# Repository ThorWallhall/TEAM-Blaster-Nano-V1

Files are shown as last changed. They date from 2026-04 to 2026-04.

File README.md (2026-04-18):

# T.E.A.M. Blaster Nano V1

**Open-source prop electronics kit for makers, cosplayers, and fandom builders.**  
**Open-Source-Elektronikkit für Maker, Cosplayer und Fandom-Bastler.**

[🇬🇧 English](#english) · [🇩🇪 Deutsch](#deutsch)

---

## English

### Overview

The T.E.A.M. Blaster Nano V1 is a compact all-in-one electronics board for
button-triggered sound and light effects in DIY props — fandom blasters,
sci-fi phasers, lightsabers and similar projects. A single button press plays
an audio sample through the onboard DFPlayer Mini while flashing an LED in sync.

### Features

- Button-triggered audio playback with synchronized LED effect
- Integrated Li-Ion battery charging over USB-C (**TP4056**)
- Battery protection circuit (**DW01A + FS8205A** dual MOSFET)
- Boost converter for a stable supply rail (**MT3608**)
- **ATmega328P-AU** microcontroller — Arduino Nano compatible
- Onboard USB-UART bridge (**CH340G**) — flash firmware directly via USB-C
- Compact form factor with JST-XH connectors for battery, speaker, button, LED

### Hardware

| Block | Part | Package |
|---|---|---|
| Microcontroller | ATmega328P-AU | TQFP-32 |
| Audio player | DFPlayer Mini (DFR0299)  | module |
| Battery charger | TP4056 | SOIC-8-1EP |
| Battery protection  | DW01A + FS8205A | SOT-23-6 + TSSOP-8 |
| Boost converter | MT3608 | SOT-23-6 |
| USB-UART bridge | CH340G | SOIC-16 |
| USB input | USB-C (GCT USB4085) | — |

Full bill of materials in `Dokumentation/`.

### Repository Structure

```
├── Code T.E.A.M. - Blaster Nano V1/   → firmware (PlatformIO / Arduino)
├── Dokumentation/                     → BOM, datasheets
├── KiCAD/                             → schematic + PCB design files
├── ASSEMBLY.md                        → ⚠️ assembly & safety notes
└── README.md                          → this file
```

### Firmware

Written in C++11 for the Arduino framework. Builds with either the Arduino IDE
or PlatformIO.

Dependencies:

- `Arduino.h` *(core)*
- `SoftwareSerial.h` *(core)*
- `DFRobotDFPlayerMini` *(install via library manager)*

### ⚠️ Assembly

**Before first power-on, read [`ASSEMBLY.md`](ASSEMBLY.md).**
It contains critical polarity information for the JST-XH connectors —
wrong polarity can destroy the battery cell or the protection circuit.

### License

MIT License — see the `LICENSE` file for details.

### Author

T.E.A.M. — *for your fandom* · © 2026

---

## Deutsch

### Überblick

Der T.E.A.M. Blaster Nano V1 ist eine kompakte All-in-One-Elektronikplatine
für taster-ausgelöste Sound- und Lichteffekte in Eigenbau-Props — Fandom-Blaster,
Sci-Fi-Phaser, Lichtschwerter und ähnliche Projekte. Ein Tastendruck spielt ein
Audio-Sample über das integrierte DFPlayer-Mini-Modul und lässt synchron dazu
eine LED aufleuchten.

### Funktionen

- Taster-ausgelöste Audio-Wiedergabe mit synchronem LED-Effekt
- Integrierte Li-Ion-Akkuladung über USB-C (**TP4056**)
- Schutzschaltung für den Akku (**DW01A + FS8205A** Dual-MOSFET)
- Step-Up-Wandler für stabile Versorgungsspannung (**MT3608**)
- **ATmega328P-AU** Mikrocontroller — Arduino-Nano-kompatibel
- Integrierter USB-UART-Bridge (**CH340G**) — Firmware direkt über USB-C flashen
- Kompaktes Format mit JST-XH-Steckern für Akku, Lautsprecher, Taster, LED

### Hardware

| Block | Bauteil | Gehäuse |
|---|---|---|
| Mikrocontroller | ATmega328P-AU | TQFP-32 |
| Audio-Player | DFPlayer Mini (DFR0299)  | Modul |
| Akku-Lader | TP4056 | SOIC-8-1EP |
| Akku-Schutz | DW01A + FS8205A | SOT-23-6 + TSSOP-8 |
| Step-Up-Wandler | MT3608 | SOT-23-6 |
| USB-UART-Bridge | CH340G | SOIC-16 |
| USB-Eingang | USB-C (GCT USB4085) | — |

Die vollständige Stückliste liegt im Ordner `Dokumentation/`.

### Repository-Struktur

```
├── Code T.E.A.M. - Blaster Nano V1/   → Firmware (PlatformIO / Arduino)
├── Dokumentation/                     → Stückliste, Datenblätter
├── KiCAD/                             → Schaltplan + PCB-Entwurfsdaten
├── ASSEMBLY.md                        → ⚠️ Montage- & Sicherheitshinweise
└── README.md                          → diese Datei
```

### Firmware

Geschrieben in C++11 für das Arduino-Framework. Lässt sich sowohl mit der
Arduino IDE als auch mit PlatformIO bauen.

Abhängigkeiten:

- `Arduino.h` *(Kern)*
- `SoftwareSerial.h` *(Kern)*
- `DFRobotDFPlayerMini` *(über Library Manager installieren)*

### ⚠️ Montage

**Vor dem ersten Einschalten unbedingt [`ASSEMBLY.md`](ASSEMBLY.md) lesen.**
Dort stehen wichtige Polungshinweise zu den JST-XH-Steckern —
falsche Polung kann den Akku oder die Schutzschaltung zerstören.

### Lizenz

MIT-Lizenz — Details in der Datei `LICENSE`.

### Autor

T.E.A.M. — *for your fandom* · © 2026

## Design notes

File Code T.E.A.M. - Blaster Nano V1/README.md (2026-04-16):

# TEAM-Blaster-Nano-V1
T.E.A.M. Blaster Nano V1 - Prop Electronics Kit

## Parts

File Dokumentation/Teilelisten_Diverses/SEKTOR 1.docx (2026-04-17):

SEKTOR 1 — POWER (final)

Bauteil | Gehäuse | Funktion
TP4056 | SOP-8 | LiPo-Lade IC
DW01A | SOT-23-6 | Akku-Schutz
FS8205A | SOT-23-6 | Dual MOSFET für DW01A
USB-C Buchse (J1) | SMD | Laden + Programmieren
14500 LiPo | — | Stromquelle
JST-XH 2,5mm (J2) | 2-Pin | Akku-Anschluss
LED rot | SMD | Ladeanzeige (CHRG)
LED grün | SMD | Vollanzeige (STDBY)
R 1kΩ | 0402 | ×2, Vorwiderstand LEDs
R 2,4kΩ | 0402 | PROG Ladestrom 500mA
C 100nF | 0402 | Bypass VCC
C 10µF | 0805 | Stützkondensator BAT

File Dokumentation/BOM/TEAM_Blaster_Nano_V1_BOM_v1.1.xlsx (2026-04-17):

T.E.A.M. Blaster Nano V1 — Bill of Materials (aus KiCad Schematic)
Rev. 1.1 | Datum: 2026-04-17 | MCU: ATmega328P-AU (TQFP-32) + CH340G | Autor: T.E.A.M. - for your fandom
Ref | Wert / Typ | Menge | Hersteller | Bestellnummer (Beispiel) | Footprint | Package | Preis/Stk (€) | Gesamt (€) | Funktion / Bemerkung
USB-Ladeschaltung (TP4056 ESOP-8)
U1 | TP4056-42-ESOP8 | 1 | NanJing Top Power | TP4056-42-ESOP8 (LCSC: C16581) | SOIC-8_3.9x4.9mm_P1.27mm | ESOP-8 | 0.25 € | 0.25 € | LiPo-Lader 4,2 V; CC/CV; Thermoschutz
J1 | USB-C Buchse 14P | 1 | GCT | USB4085-GF-A | USB_C_Receptacle_GCT_USB4085 | SMD 14-Pin | 0.55 € | 0.55 € | Ladeeingang 5 V USB
R3 | 2k4 | 1 | Yageo | RC0402FR-072K4L | R_0402_1005Metric | 0402 | 0.02 € | 0.02 € | RPROG → I_CHG = 1200/2,4 = 500 mA
R10, R11 | 5k1 | 2 | Yageo | RC0402FR-075K1L | R_0402_1005Metric | 0402 | 0.02 € | 0.04 € | USB-C CC1/CC2 Pull-down (5,1 kΩ je)
D1 | LED rot | 1 | Würth | 150080RS75000 | LED_0805_2012Metric | 0805 | 0.05 € | 0.05 € | Charging-Status (TP4056 Pin CHRG)
D2 | LED blau | 1 | Würth | 150080BS75000 | LED_0805_2012Metric | 0805 | 0.06 € | 0.06 € | Standby/Full-Status (TP4056 Pin STDBY)
R1 | 1k (LED CHG) | 1 | Yageo | RC0402FR-071KL | R_0402_1005Metric | 0402 | 0.02 € | 0.02 € | Strombegrenzung D1
R2 | 1k (LED STDBY) | 1 | Yageo | RC0402FR-071KL | R_0402_1005Metric | 0402 | 0.02 € | 0.02 € | Strombegrenzung D2
C1 | 10 µF / 10 V | 1 | Murata | GRM21BR61A106KE19L | C_0805_2012Metric | 0805 | 0.08 € | 0.08 € | TP4056 VCC-Bypass
Batterieschutz (DW01A + FS8205A)
U2 | DW01A | 1 | Fortune Semi | DW01A-G | SOT-23-6 | SOT-23-6 | 0.12 € | 0.12 € | Über-/Unterspannungs- & Überstromschutz LiPo
Q1 | FS8205A | 1 | Fortune Semi | FS8205A | SOT-23-6 | SOT-23-6 | 0.18 € | 0.18 € | Dual N-Ch MOSFET; Lade-/Entlade-Schalter
R4 | 0,47 Ω | 1 | Yageo | RC0402FR-070R47L | R_0402_1005Metric | 0402 | 0.03 € | 0.03 € | Strommess-Shunt (CS-Pin DW01A)
R5 | 470 Ω | 1 | Yageo | RC0402FR-07470RL | R_0402_1005Metric | 0402 | 0.02 € | 0.02 € | ESD-Schutz VCC-Pin DW01A
J2 | JST XH 2-Pin (Batterie) | 1 | JST | B2B-XH-A | JST_XH_B2B-XH-A_1x02_P2.50mm_Vertical | THT | 0.20 € | 0.20 € | LiPo-Akkuanschluss 3,7 V
Spannungsbooster 3,7 V → ~4,6 V (MT3608)
U3 | MT3608 | 1 | Aerosemi | MT3608 (LCSC: C84697) | SOT-23-6 | SOT-23-6 | 0.20 € | 0.20 € | Step-Up; Vout=0,6×(1+R7/R8)=0,6×7,67≈4,6 V
L1, L2 | 10 µH / 1,5 A | 2 | Würth | 744043010 | L_0805_2012Metric | 0805 | 0.28 € | 0.56 € | Boost-Spulen parallel → höhere Stromtragfähigkeit
D3 | SS14 | 1 | Vishay | SS14-E3/61T | D_SMA | SMA (DO-214AC) | 0.10 € | 0.10 € | Freilaufdiode MT3608; 40 V / 1 A
C4 | 22 µF / 16 V | 1 | Murata | GRM21BR61C226ME44L | C_0805_2012Metric | 0805 | 0.12 € | 0.12 € | MT3608 Eingangs-Puffer
C5 | 22 µF / 16 V | 1 | Murata | GRM21BR61C226ME44L | C_0805_2012Metric | 0805 | 0.12 € | 0.12 € | MT3608 Ausgangs-Glättung
R7 | 180 kΩ | 1 | Yageo | RC0402FR-07180KL | R_0402_1005Metric | 0402 | 0.02 € | 0.02 € | Feedback-Teiler oben (Vout einstellen)
R8 | 27 kΩ | 1 | Yageo | RC0402FR-0727KL | R_0402_1005Metric | 0402 | 0.02 € | 0.02 € | Feedback-Teiler unten
Mikrocontroller ATmega328P-AU + CH340G
U4 | ATmega328P-AU | 1 | Microchip | ATMEGA328P-AU | TQFP-32_7x7mm_P0.8mm | TQFP-32 | 1.80 € | 1.80 € | Haupt-MCU; 16 MHz; 5 V; Arduino-kompatibel
U5 | CH340G | 1 | WCH | CH340G | SOIC-16_3.9x9.9mm_P1.27mm | SOIC-16 | 0.35 € | 0.35 € | USB-Seriell-Brücke für Programmierung
Y1 | 16 MHz | 1 | ABRACON | ABM3-16.000MHZ-D2Y-T | Crystal_SMD_3225-4Pin_3.2x2.5mm | SMD 3225 | 0.35 € | 0.35 € | Takt ATmega328P
Y2 | 12 MHz | 1 | ABRACON | ABM3-12.000MHZ-D2Y-T | Crystal_SMD_3225-4Pin_3.2x2.5mm | SMD 3225 | 0.35 € | 0.35 € | Takt CH340G
C11, C12 | 22 pF / 50 V | 2 | Samsung | CL05C220JB5NNNC | C_0402_1005Metric | 0402 | 0.03 € | 0.06 € | Load-Caps Y1 (ATmega)
C13, C14 | 22 pF / 50 V | 2 | Samsung | CL05C220JB5NNNC | C_0402_1005Metric | 0402 | 0.03 € | 0.06 € | Load-Caps Y2 (CH340G)
C2, C8 | 10 µF / 10 V | 2 | Murata | GRM21BR61A106KE19L | C_0805_2012Metric | 0805 | 0.08 € | 0.16 € | VCC-Bypass MCU / CH340G
C3,C6,C7,C9,C10,C15,C16 | 100 nF / 10 V | 7 | Samsung | CL05B104KO5NNNC | C_0402_1005Metric | 0402 | 0.03 € | 0.21 € | Entkopplungs-Caps (verteilt auf alle ICs)
R9 | 10 kΩ | 1 | Yageo | RC0402FR-0710KL | R_0402_1005Metric | 0402 | 0.02 € | 0.02 € | RESET Pull-up ATmega328P
J6 | ISP 2×3 Pfostenleiste | 1 | Würth | 61300621121 | PinHeader_2x03_P2.54mm_Vertical | THT 2,54 mm | 0.15 € | 0.15 € | In-System-Programmierung (MOSI/MISO/SCK/RST)
Audio (DFPlayer Mini DFR0299)
U6 | DFR0299 DFPlayer Mini | 1 | DFRobot | DFR0299 | MODULE_DFR0299 (Custom) | Modul | 2.80 € | 2.80 € | MP3/WAV; UART 9600; interner SD-Kartenleser
R6 | 1 kΩ (UART-RX) | 1 | Yageo | RC0402FR-071KL | R_0402_1005Metric | 0402 | 0.02 € | 0.02 € | Pegelschutz ATmega TX → DFPlayer RX
J3 | JST XH 2-Pin (LED) | 1 | JST | B2B-XH-A | JST_XH_B2B-XH-A_1x02_P2.50mm_Vertical | THT | 0.20 € | 0.20 € | Externer Blaster-LED-Anschluss
J4 | JST XH 2-Pin (Taster) | 1 | JST | B2B-XH-A | JST_XH_B2B-XH-A_1x02_P2.50mm_Vertical | THT | 0.20 € | 0.20 € | Trigger-Taster extern; Pin D3
J5 | JST XH 2-Pin (Speaker) | 1 | JST | B2B-XH-A | JST_XH_B2B-XH-A_1x02_P2.50mm_Vertical | THT | 0.20 € | 0.20 € | Lautsprecher 8 Ω an DFPlayer SPK1/SPK2
GESAMTKOSTEN (Einzelplatine, ohne Akku & Lautsprecher) |  |  |  |  |  |  |  | 9.71 € | Ohne MwSt. / ohne Versand / Richtpreise
⚠ Hinweise: R3=2k4 → I_CHG=500 mA (TP4056). L1+L2 je 10 µH parallel → erhöhte Stromtragfähigkeit. Vout(MT3608) = 0,6×(1+180k/27k) ≈ 4,6 V. Q1 (FS8205A) hat SOT-23-6 Footprint laut CSV (nicht TSSOP-8). Y2=12 MHz ist der Takt für den CH340G USB-Seriell-Chip. R10/R11 = 5k1 sind USB-C CC-Pull-downs (Pflicht für USB-C Power).

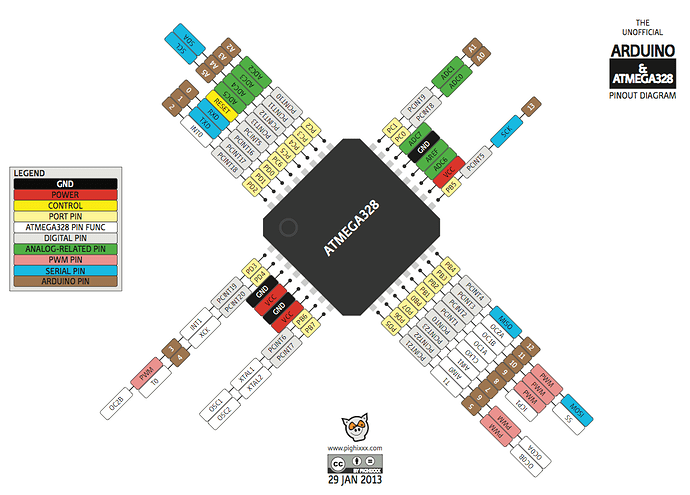
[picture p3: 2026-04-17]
Dokumentation/Teilelisten_Diverses/5d795ff3e6a315c0eee8202d54d3cbbd91941882_2_690x495.png

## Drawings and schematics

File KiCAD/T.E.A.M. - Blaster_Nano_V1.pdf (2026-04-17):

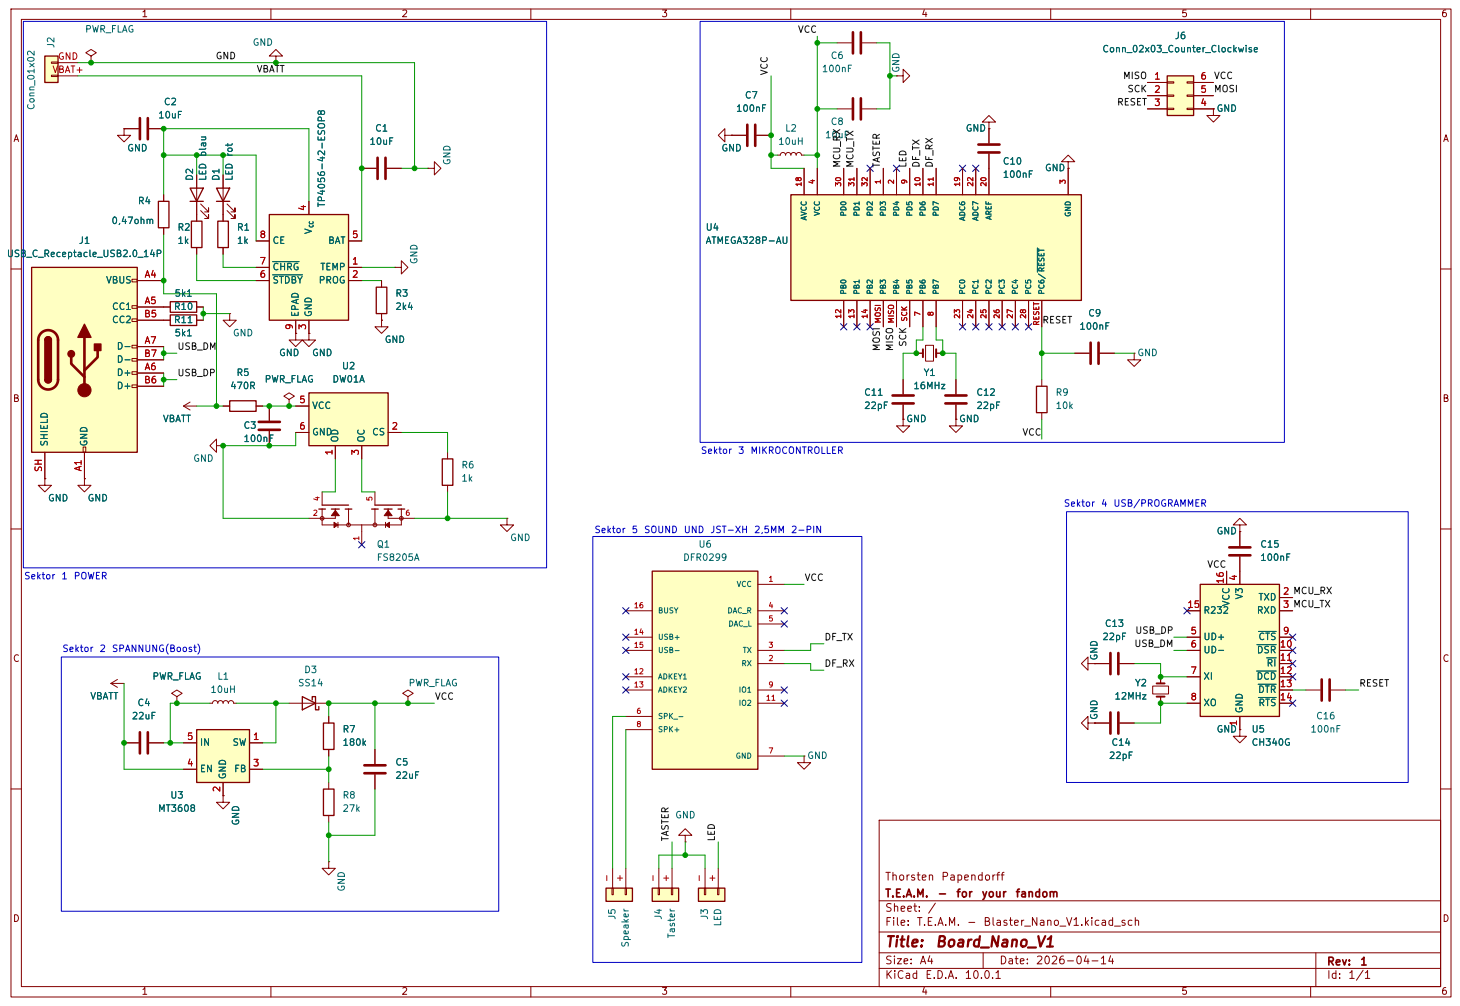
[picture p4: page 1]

MOSI Sektor 5 SOUND UND JST-XH 2,5MM 2-PIN

9 PD6 10 PD7 11 PB0 12 PB1 13 PB2 14 AVCC 18 ADC6 19 AREF 20 ADC7 22 PC0 23 PC1 24 PC2 25 PC3 26 PC4 27 PC5 28 PD0 30 PD1 31 PD2 32 PB4 MISO PB3 MOSI PC6/ RESET RESET PB5 SCK C7
GND U4

9 PD6 10 PD7 11 PB0 12 PB1 13 PB2 14 AVCC 18 ADC6 19 AREF 20 ADC7 22 PC0 23 PC1 24 PC2 25 PC3 26 PC4 27 PC5 28 PD0 30 PD1 31 PD2 32 PB4 MISO PB3 MOSI PC6/ RESET RESET PB5 SCK U4

Size: A4 | Rev: 1
KiCad E.D.A. 10.0.1 | Id: 1/1

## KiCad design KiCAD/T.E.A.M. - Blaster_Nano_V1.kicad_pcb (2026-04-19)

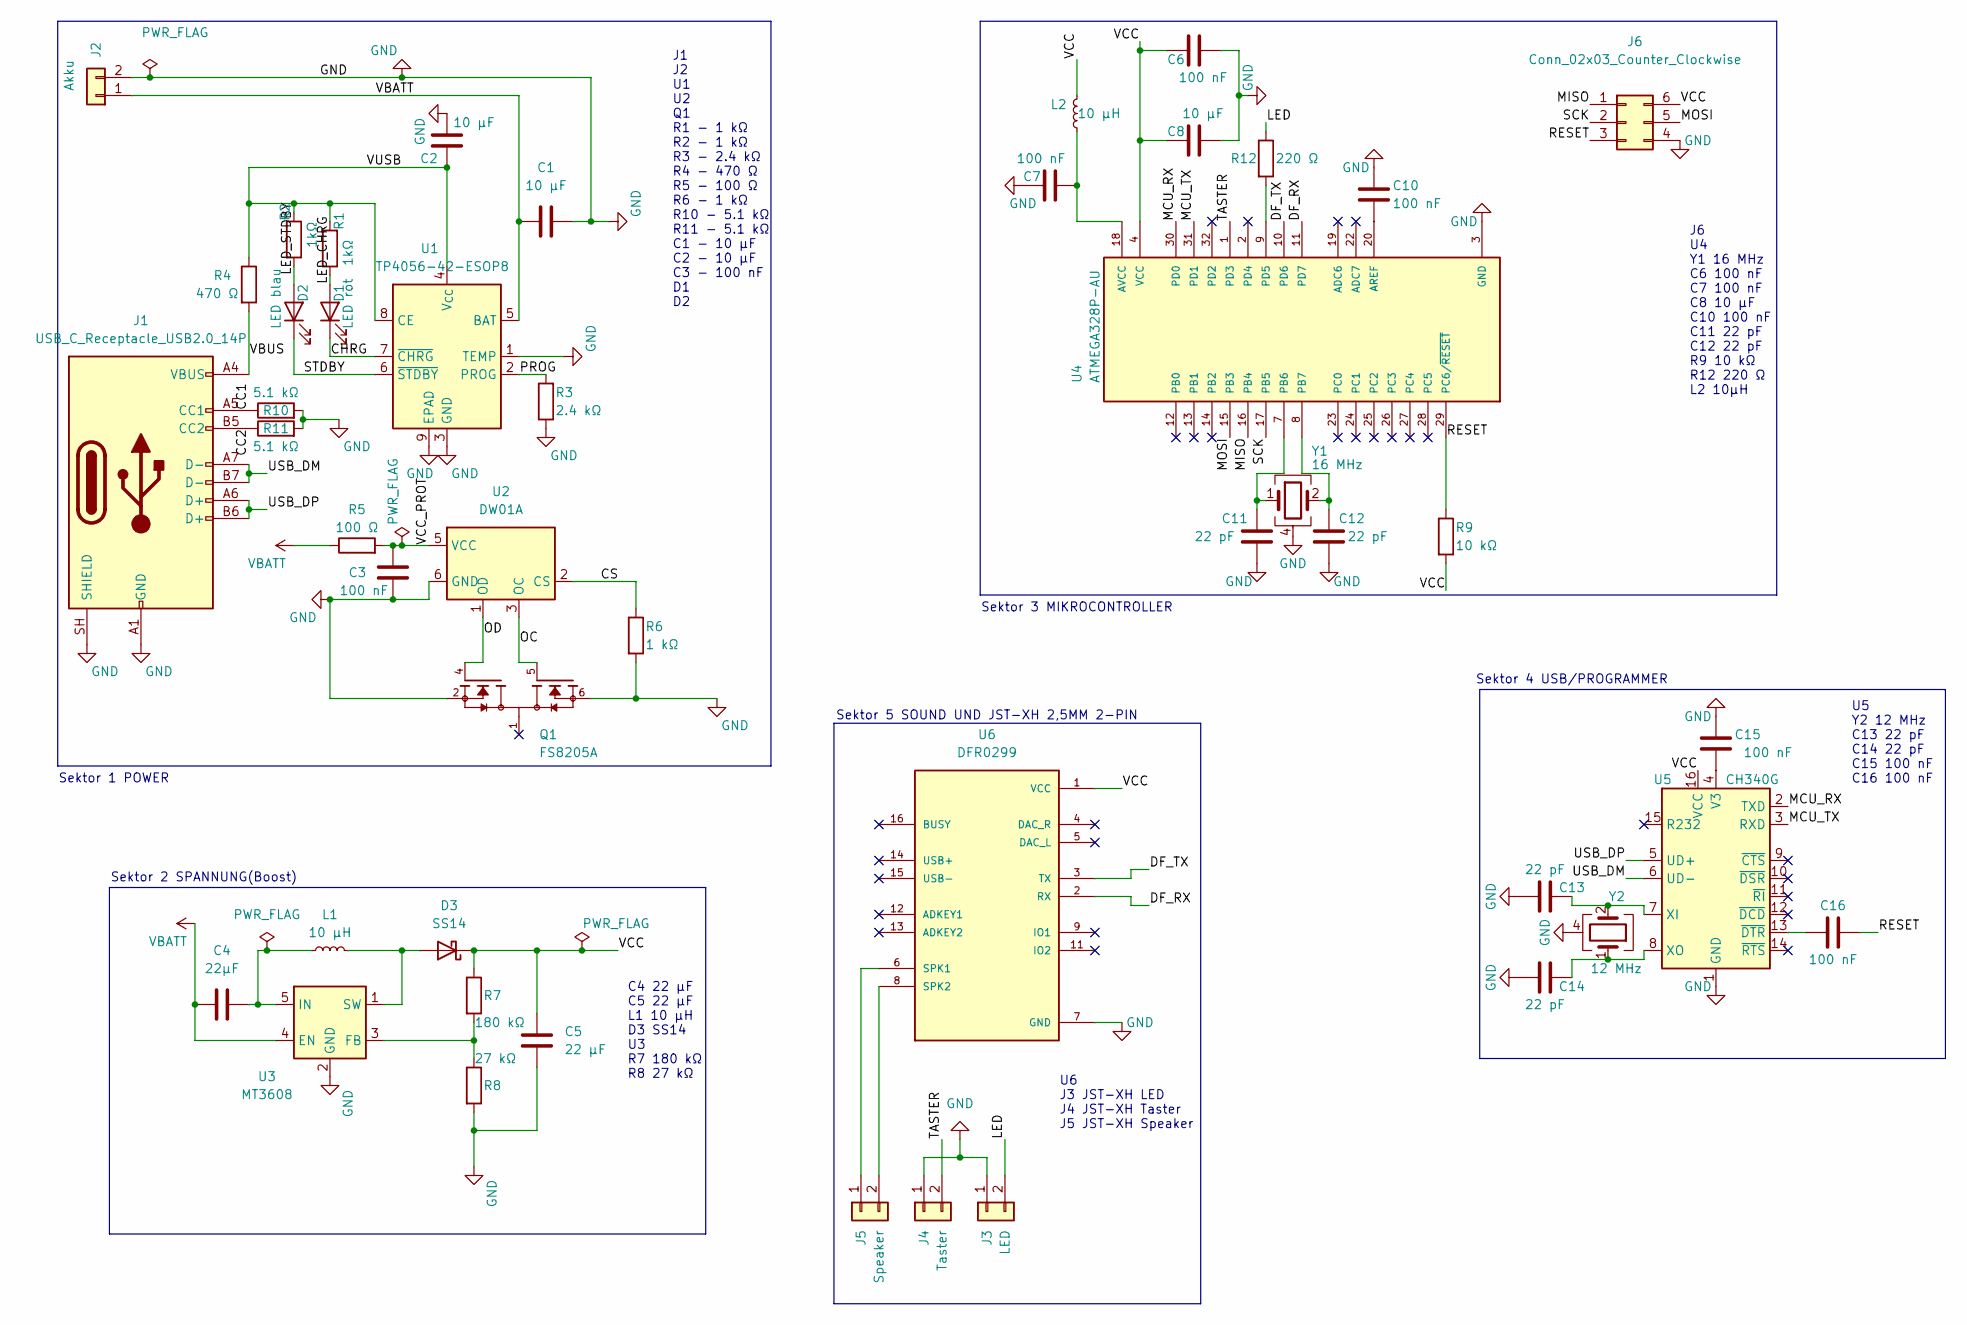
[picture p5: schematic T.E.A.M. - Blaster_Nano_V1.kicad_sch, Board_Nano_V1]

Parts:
C1, C2, C8: 10 µF; C_0805_2012Metric
C3, C6, C7, C10, C15, C16: 100 nF; C_0402_1005Metric
C4: 22µF; C_0805_2012Metric
C5: 22 µF; C_0805_2012Metric
C11, C12, C13, C14: 22 pF; C_0402_1005Metric
D1: LED rot; LED_0805_2012Metric
D2: LED blau; LED_0805_2012Metric
D3: SS14; D_SMA
J1: USB_C_Receptacle_USB2.0_14P; USB_C_Receptacle_GCT_USB4085
J2: Akku; JST_XH_B2B-XH-A_1x02_P2.50mm_Vertical
J3: LED; JST_XH_B2B-XH-A_1x02_P2.50mm_Vertical
J4: Taster; JST_XH_B2B-XH-A_1x02_P2.50mm_Vertical
J5: Speaker; JST_XH_B2B-XH-A_1x02_P2.50mm_Vertical
J6: Conn_02x03_Counter_Clockwise; PinHeader_2x03_P2.54mm_Vertical
L1, L2: 10 µH; L_0805_2012Metric
Q1: FS8205A; TSSOP-8_4.4x3mm_P0.65mm; PARTREV 1.7
R1, R2: 1kΩ; R_0402_1005Metric
R3: 2.4 kΩ; R_0402_1005Metric
R4: 470 Ω; R_0402_1005Metric
R5: 100 Ω; R_0402_1005Metric
R6: 1 kΩ; R_0402_1005Metric
R7: 180 kΩ; R_0402_1005Metric
R8: 27 kΩ; R_0402_1005Metric
R9: 10 kΩ; R_0402_1005Metric
R10, R11: 5.1 kΩ; R_0402_1005Metric
R12: 220 Ω
U1: TP4056-42-ESOP8; SOIC-8-1EP_3.9x4.9mm_P1.27mm_EP2.41x3.3mm_ThermalVias
U2: DW01A; SOT-23-6
U3: MT3608; SOT-23-6
U4: ATMEGA328P-AU; QFP80P900X900X120-32N; PARTREV 8271A
U5: CH340G; SOIC-16_3.9x9.9mm_P1.27mm
U6: DFR0299; MODULE_DFR0299
Y1: 16 MHz; Crystal_SMD_3225-4Pin_3.2x2.5mm
Y2: 12 MHz; Crystal_SMD_3225-4Pin_3.2x2.5mm

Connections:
/CC1: J1.A5 (CC1), R10.1
/CC2: J1.B5 (CC2), R11.1
/CHRG: D1.1 (K), U1.7 (~CHRG)
/CS: R6.1, U2.2 (CS)
/DF_RX: U4.11 (PD7), U6.2 (RX)
/DF_TX: U4.10 (PD6), U6.3 (TX)
/LED: J3.2, R12.1
/LED_CHRG: D1.2 (A), R1.1
/LED_STDBY: D2.2 (A), R2.2
/MCU_RX: U4.30 (PD0), U5.2 (TXD)
/MCU_TX: U4.31 (PD1), U5.3 (RXD)
/MISO: J6.1, U4.16 (PB4)
/MOSI: J6.5, U4.15 (PB3)
/OC: Q1.5, U2.3 (OC)
/OD: Q1.4, U2.1 (OD)
/PROG: R3.2, U1.2 (PROG)
/RESET: C16.2, J6.3, R9.1, U4.29 (PC6/~RESET)
/SCK: J6.2, U4.17 (PB5)
/STDBY: D2.1 (K), U1.6 (~STDBY)
/TASTER: J4.2, U4.1 (PD3)
/USB_DM: J1.A7 (D-), J1.B7 (D-), U5.6 (UD-)
/USB_DP: J1.A6 (D+), J1.B6 (D+), U5.5 (UD+)
/VBUS: J1.A4 (VBUS), J1.A9 (VBUS), J1.B4 (VBUS), J1.B9 (VBUS), R4.2
/VCC_PROT: C3.1, R5.2, U2.5 (VCC)
/VUSB: C2.2, R1.2, R2.1, R4.1, U1.4 (V_{CC}), U1.8 (CE)
GND: C1.2, C2.1, C3.2, C5.2, C6.2, C7.1, C8.2, C10.1, C11.2, C12.2, C13.1, C14.1, C15.1, J1.A1 (GND), J1.A12 (GND), J1.B1 (GND), J1.B12 (GND), J1.SH (SHIELD), J2.2, J3.1, J4.1, J6.4, Q1.2, Q1.3, Q1.6, Q1.7, R3.1, R6.2, R8.2, R10.2, R11.2, U1.1 (TEMP), U1.3 (GND), U1.9 (EPAD), U2.6 (GND), U3.2 (GND), U4.3 (GND), U4.5 (GND), U4.21 (GND), U5.1 (GND), U6.7 (GND), U6.10 (GND), Y1.3 (G), Y1.4 (G), Y2.3 (G), Y2.4 (G)
unnamed: D3.2 (A), L1.2, U3.1 (SW)
unnamed: J5.1, U6.6 (SPK1)
unnamed: J5.2, U6.8 (SPK2)
unnamed: R7.2, R8.1, U3.3 (FB)
unnamed: C4.2, L1.1, U3.5 (IN)
unnamed: C10.2, U4.20 (AREF)
unnamed: C7.2, L2.1, U4.18 (AVCC)
unnamed: C11.1, U4.7 (PB6), Y1.1
unnamed: C12.1, U4.8 (PB7), Y1.2 (4)
unnamed: R12.2, U4.9 (PD5)
unnamed: C15.2, U5.4 (V3)
unnamed: C13.2, U5.7 (XI), Y2.2 (4)
unnamed: C14.2, U5.8 (XO), Y2.1
unnamed: C16.1, U5.13 (~DTR)
VBATT: C1.1, C4.1, J2.1, R5.1, U1.5 (BAT), U3.4 (EN)
VCC: C5.1, C6.1, C8.1, D3.1 (K), J6.6, L2.2, R7.1, R9.2, U4.4 (VCC), U4.6 (VCC), U5.16 (VCC), U6.1 (VCC)

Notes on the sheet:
Sektor 5 SOUND UND JST-XH 2,5MM 2-PIN
Sektor 4 USB/PROGRAMMER
C4 22 µF C5 22 µF L1 10 µH D3 SS14 U3 R7 180 kΩ R8 27 kΩ
U5 Y2 12 MHz C13 22 pF C14 22 pF C15 100 nF C16 100 nF
U6 J3 JST-XH LED J4 JST-XH Taster J5 JST-XH Speaker
Sektor 1 POWER
Sektor 3 MIKROCONTROLLER
J1 J2 U1 U2 Q1 R1 - 1 kΩ R2 - 1 kΩ R3 - 2.4 kΩ R4 - 470 Ω R5 - 100 Ω R6 - 1 kΩ R10 - 5.1 kΩ R11 - 5.1 kΩ C1 - 10 µF C2 - 10 µF C3 - 100 nF D1 D2
Sektor 2 SPANNUNG(Boost)
J6 U4 Y1 16 MHz C6 100 nF C7 100 nF C8 10 µF C10 100 nF C11 22 pF C12 22 pF R9 10 kΩ R12 220 Ω L2 10µH

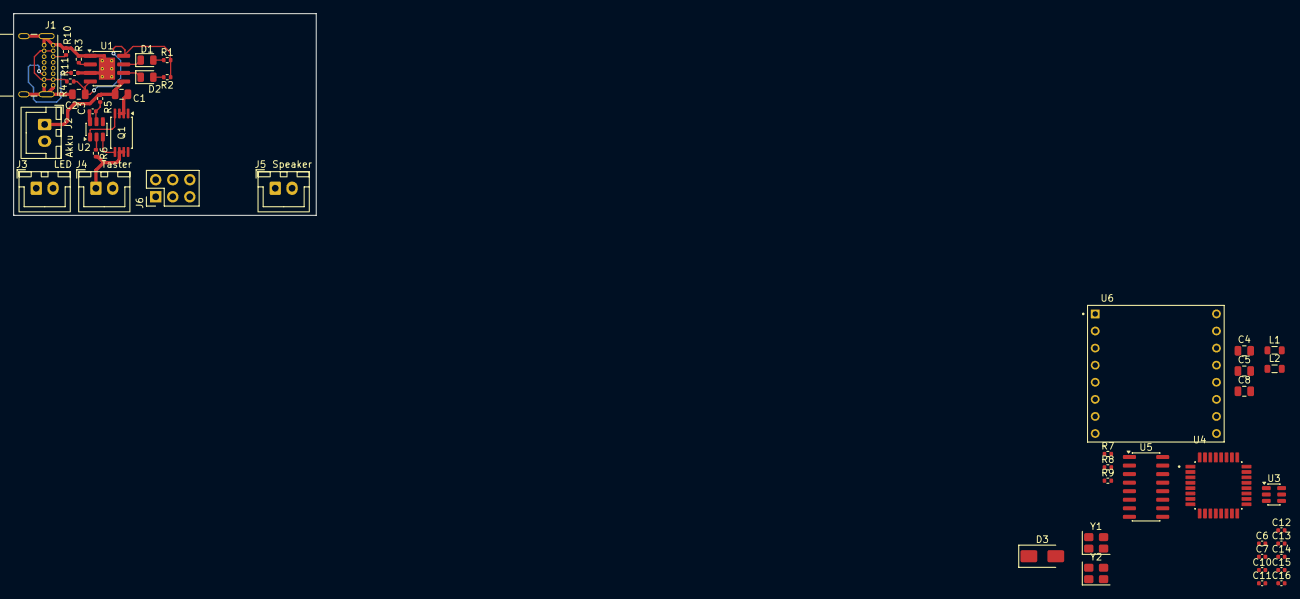
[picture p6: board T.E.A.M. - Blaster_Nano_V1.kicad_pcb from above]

Board: 2 copper layers, 45.0 x 30.0 mm, 46 parts (0 on the bottom side), 40 nets.

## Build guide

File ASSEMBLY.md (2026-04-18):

# Montage — T.E.A.M. Blaster Nano V1

## ⚠️ JST-XH Polung

> **Wichtig beim Selbst-Crimpen oder Umstecken fertiger Kabel.**

Aus PCB-Routing-Gründen sind die JST-XH-Stecker auf dieser Platine
teilweise **umgekehrt zur üblichen Konvention** belegt.

### Pinbelegung Platinenseite

| Stecker | Funktion | Pin 1 | Pin 2 |
|---|---|---|---|
| **J2**  | Li-Ion Akku | VBAT+ (rot) | GND (schwarz) |
| **J3**  | externe LED | LED− (Kathode) | LED+ (Anode) |
| **J4**  | Taster | GND- | TASTER Signal |
| **J5**  | Lautsprecher | SPK− | SPK+ |

### ⚠️ Pflicht-Check vor erstem Einschalten

1. Multimeter auf DC-Spannungsmessung (Bereich 20 V)
2. Akku in **J2** einstecken
3. Rote Messspitze an **J2 Pin 1 (VBAT+)**,
   schwarze Messspitze an **J2 Pin 2 (GND)**
4. Anzeige muss **zwischen +3,0 V und +4,2 V** liegen
5. **Bei negativem Vorzeichen: Akku sofort abziehen — Polung falsch**

#### Folgen einer Verpolung an J2

- Schutzbeschaltung (**DW01A + FS8205A**) wird zerstört
- Akkuzelle kann dauerhaft Kapazität verlieren
- Im schlimmsten Fall: **Zellenbrand / Gasausdehnung**

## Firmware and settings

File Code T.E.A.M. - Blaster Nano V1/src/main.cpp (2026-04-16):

// This file is part of the T.E.A.M. Blaster Nano V1 project 
// Copyright (c) 2026 T.E.A.M. - for your fandom All rights reserved.
// This project is licensed under the MIT License - see LICENSE file for details.
// Author: T.E.A.M. - for your fandom
// This file is the main entry point for the T.E.A.M. Blaster Nano V1 firmware.
// It initializes the hardware and starts the main loop of the program.
// Note: This code is written in C++11 and is intended to run on an Arduino Nano with an ATmega328P microcontroller.
// Include the Arduino library for basic functions and definitions.
// Note: The Arduino library provides functions for digital and analog I/O, timing, and other basic operations.
// Note: The Arduino library is included by default in the Arduino IDE, but it must be explicitly included in PlatformIO projects.
// Date: 2026-04-16

#include <Arduino.h>
#include <SoftwareSerial.h>
#include <DFRobotDFPlayerMini.h>

SoftwareSerial mySoftwareSerial(10, 11); // RX, TX pins for the DFPlayer Mini
DFRobotDFPlayerMini myDFPlayer;

#define PIN_TASTER 3
#define PIN_LED 5

int flashtime = 350; // Flash time in milliseconds

void setup() {
  // Initialize the software serial communication for the DFPlayer Mini.
  mySoftwareSerial.begin(9600);
  myDFPlayer.begin(mySoftwareSerial);
  myDFPlayer.volume(28); // Set volume to maximum (0-30)

  // Set the pin modes for the button and LED.
  pinMode(PIN_TASTER, INPUT_PULLUP); // Button connected to pin 3 with internal pull-up resistor
  pinMode(PIN_LED, OUTPUT); // LED connected to pin 5

  // short LED flash to indicate that the setup is complete
  digitalWrite(PIN_LED, HIGH);
  delay(flashtime);
  digitalWrite(PIN_LED, LOW);
}

void loop() {
  // Check if the button is pressed (active LOW)
  if (digitalRead(PIN_TASTER) == LOW) {
    // Play the sound file "1.mp3" from the DFPlayer Mini
    myDFPlayer.play(1); // Play the first track on the SD card

    // Flash the LED while the sound is playing
      digitalWrite(PIN_LED, HIGH);
      delay(flashtime);
      digitalWrite(PIN_LED, LOW);
      // delay(flashtime);
  }
}

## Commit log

2026-04-16 Update platformio.ini: change board type to nanoatmega328new and increase upload speed to 115200
2026-04-17 KiCAD Sektor 1 POWER - Bauteile platziert, J2 verdrahtet.
    [Blaster_Nano_v1_fritzing.fzz, T.E.A.M. - Blaster_Nano_V1.kicad_pcb, T.E.A.M. - Blaster_Nano_V1.kicad_sch]
2026-04-17 Sektor 1 POWER - DW01A verdrahtet.
    [T.E.A.M. - Blaster_Nano_V1.kicad_sch]
2026-04-17 Update: .gitignore KiCAD Backups und Lock Dateien ignorieren.
2026-04-17 Cleanup: Backup und Lock Dateien entfernt.
2026-04-17 Sektor 1 POWER -vollständig verdrahtet und eingerahmt.
    [T.E.A.M. - Blaster_Nano_V1.kicad_sch]
2026-04-17 Sektor 2 SPANNUNG - MT3608 fertig verdrahtet.
    [T.E.A.M. - Blaster_Nano_V1.kicad_sch]
2026-04-17 Sektor 3 MIKROCONTROLLER - ATmega328P-Au und 6 Pinheader verdrahtet.
    [T.E.A.M. - Blaster_Nano_V1.kicad_sch]
2026-04-17 Sektor 4 USB/PROGRAMMER - CH340G verdrahtet.
    [T.E.A.M. - Blaster_Nano_V1.kicad_sch]
2026-04-17 Sektor 5 SOUND UND JST-XH 2,5MM 2-PIN verdrahtet.
    [T.E.A.M. - Blaster_Nano_V1.kicad_sch]
2026-04-17 ERC bereinigt - 0 Fehler, 4 Footprints Warnungen.
    [T.E.A.M. - Blaster_Nano_V1.kicad_sch]
2026-04-17 Netzklassen erstellt und zugeordnet.
2026-04-17 Footprints zugewiesen - alle Bauteile komplett.
    [T.E.A.M. - Blaster_Nano_V1.kicad_sch]
2026-04-17 BOM erstellt und heruntergeladen.
    [T.E.A.M. - Blaster_Nano_V1.csv, T.E.A.M. - Blaster_Nano_V1.kicad_sch, TEAM_Blaster_Nano_V1_BOM_v1.1.xlsx]
2026-04-18 .gitignore erweitert: kicad_prl und Tilde-Lock_Dateien ausgeschlossen
2026-04-18 Add assembly instructions and safety warnings
    Document important assembly information and safety checks for the T.E.A.M. Blaster Nano V1.
2026-04-18 Add README for T.E.A.M. Blaster Nano V1
    Added detailed information about the T.E.A.M. Blaster Nano V1, including features, hardware specifications, repository structure, firmware details, assembly instructions, and licensing.
2026-04-18 Fix schematic pin numbers (J2-J5) and footprint references (Q1, Y1, Y2, U6)
    [T.E.A.M. - Blaster_Nano_V1.kicad_pcb, T.E.A.M. - Blaster_Nano_V1.kicad_sch]
2026-04-18 Add Crystal_GND31 symbol and connect crystal shield to GND
    [T.E.A.M. - Blaster_Nano_V1.kicad_pcb, T.E.A.M. - Blaster_Nano_V1.kicad_sch]
2026-04-18 Add 3D models for U1, U4, U6
    [T.E.A.M. - Blaster_Nano_V1.kicad_pcb]
2026-04-18 Add Aisler 2-layer HASL design rules
    [T.E.A.M. - Blaster_Nano_V1.kicad_pcb]
2026-04-18 Add fiducial markers for SMD assembly
    [T.E.A.M. - Blaster_Nano_V1.kicad_pcb]
2026-04-18 Set net class trace widths (Power 0.5mm, USB 0.2mm)
    [T.E.A.M. - Blaster_Nano_V1.kicad_pcb]
2026-04-18 Add GND copper zones on F.Cu and B.Cu
    [T.E.A.M. - Blaster_Nano_V1.kicad_pcb]
2026-04-18 PCB Routing Zwischenstand
    [T.E.A.M. - Blaster_Nano_V1.kicad_pcb]
2026-04-19 Schaltplan finalisiert: alle Sektoren abgeschlossen
    [T.E.A.M. - Blaster_Nano_V1.kicad_pcb, T.E.A.M. - Blaster_Nano_V1.kicad_sch]
2026-04-19 gitignore erweitert: Excel temp und Report-Dateien ausgeschlossen
2026-04-19 Sektor 1: Placement und Routing abgeschlossen
    [T.E.A.M. - Blaster_Nano_V1.kicad_pcb, T.E.A.M. - Blaster_Nano_V1.kicad_sch]
